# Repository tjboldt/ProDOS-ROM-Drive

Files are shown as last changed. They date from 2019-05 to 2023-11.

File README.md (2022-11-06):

# v4.0
This is a new revision of the hardware, incompatible with previous firmware and drive image before v3. If you have a v2.5 board, see the v2.5 tag [here](https://github.com/tjboldt/ProDOS-ROM-Drive/tree/v2.5). Note that all of v2.1, v2.5 and v3.0 have a small design mistake that didn't properly buffer the data bus the way it was intended in the original v1.0 version. This has been fixed for v4.0.

# ProDOS ROM-Drive
This is a peripheral card for the Apple ][ series computers that acts as a read-only solid state disk drive (SSD) all in EPROM. Although it won't run DOS, it is fully ProDOS compatible and will appear as a read-only hard drive even when booting from another drive. It holds 1024 KB of disk data with the 256 byte firmware stored in block 0001 where the SOS boot loader normally resides. The drive boots ProDOS and into BASIC in under 1.5 seconds. 

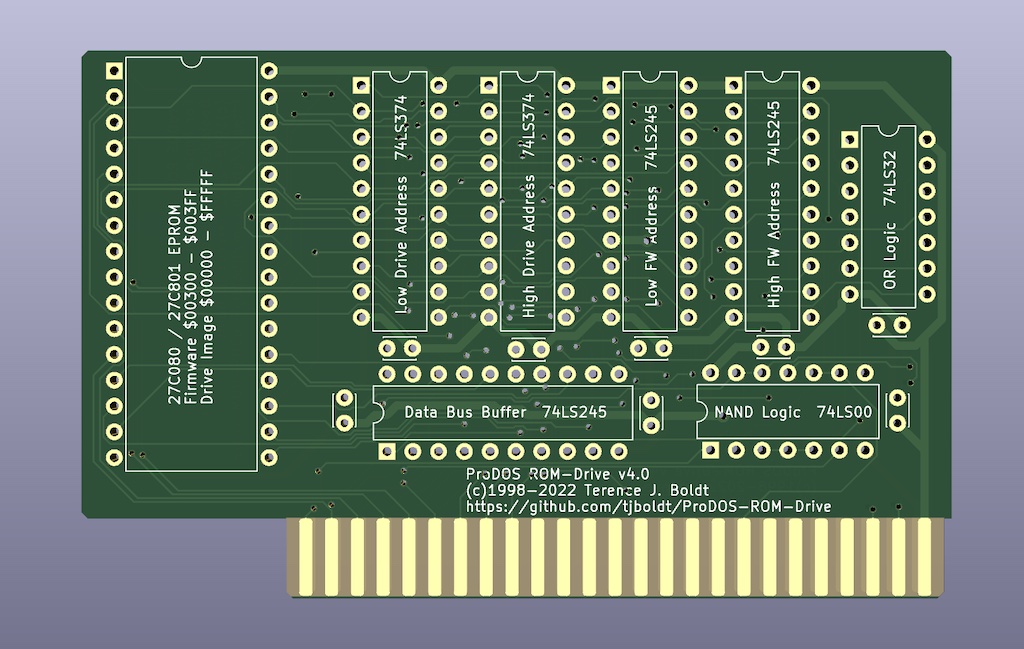
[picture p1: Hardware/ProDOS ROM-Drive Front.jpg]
Image of Board


You can order blank circuit boards from [PCBWay](https://www.pcbway.com/project/shareproject/ProDOS_ROM_Drive_v4_4fe0794f.html) or upload the provided gerber and drill files to any PCB manufacturer.

## History

My first Apple computer was an Apple //e that my brother bought in early 1984. Countless hours were spent playing games which developed my interest in building games. This also led to the creation of various utilities to help organize disks or just to see what could be done while programming.

As time passed, I obtained other machines far more powerful and eventually my once loved Apple IIe got used less and less. I did still pull it out of storage every few months to play some classic games or see what I could accomplish with greater programming skills. The problem was connecting up disk drives, looking for disks and hoping that the disks still worked. To make life simpler, I decided I needed to come up with some way to permanently store the files inside the computer without needing to plug in anything but the power and video connectors. This is where the idea for a solid-state drive began.

In the summer of 1998 I did some research in my own Apple II library for information on building peripheral cards. I drew up some designs in September 1998 and started building a prototype on a solderless breadboard with the wires jumpered over from a dead parallel card which I had cut the traces on. The rough idea at the time was to have two EPROMs. One would hold the 256 bytes of code in the $Cs00 - $CsFF space (where s is the slot number) and the second EPROM would get accessed through the 16 byte port space for the slot. To access more than 16 bytes, I would have a couple latch chips where you could program in the address of the disk EPROM and then read it one byte at a time through the ports. Originally I was going to make my own modified version of DOS 3.3 but before I got too far, David Wilson from Australia convinced me that it was much easier to build it for ProDOS since it supported many types of drives natively.

By November 1998 I had a prototype on the solderless breadboard that could read data from the EPROM but it had no driver code, didn't boot and was very unreliable. In December I managed to have the two EPROM based system running but it would fail to boot about 80% of the time with various read errors. Shortening the length of wires, cleaning up the layout and a new design helped but it was still unreliable. I finally gave up on the second design but as it turns out, it could have been fixed quite easily.

By mid-May of 1999 I finally got around to building a third design. This time I reduced the chip count and made the firmware for the drive reside in the top two blocks of the virtual disk EPROM. It still was somewhat unreliable in slot one but it was progressively worse as it was placed into higher slot numbers. By slot seven the card was completely unuseable. I then discovered that adding a 104 ceramic capacitor to each chip made the problem disappear. It was suddenly fully reliable.

To build actual circuit boards, I tried making some by hand with marker, etching solution and copper on fibreglass boards but this proved to be far too difficult. I then learned the wonders of gerber files which can be created with a variety of PCB layout software. The files were emailed to a company in Alberta, Canada and three days later in July of 1999 I received a batch of 10 blank boards. These boards did not have the familiar green board look to them, nor were they pre-cut. I had to cut and file them to fit an Apple II slot by hand. Back then it was prohitively expensive for a young hobbiest to make less than 20 or 30 boards with the full solder-masking process due to the set-up fees.

In 2019, I decided to revisit the original design as I was disappointed that the original didn't have a solder mask and was rather large for what it was. I got the board much smaller but in the process of translating my two decade old hand written notes, I made a mistake on one control line. To actually call this project finished, I had to make another revision. I also noticed the revised board was slightly larger than a credit card so I worked for a couple weeks to optimize the lines and squeeze the two-layer board down to 3.375" x 2.125". (Note that references above to first, second and third design are all the solderless breadboard prototypes leading up to the 1.0 circuit board printed in 1999, 2.0 was never made, 2.1 is the board with the error patched with a jumper wire and 2.2 through 2.4 were never made).

In 2021, the first ever issue was opened on the project requesting that the firmware be relocatable. I let that issue sit for a few months and then Ralle Palaveev supplied some relocatable firmware as a patch. I quickly realized that this could be placed into the second block on the drive normally reserved for SOS bootloader for the Apple ///, essentially allowing the full EPROM to be used for the drive. I disassembed Ralle's patch, merged it into the existing source code and made a few updates to save a few bytes and add clarity. This change required some differences in wiring for the firmware addressing on the card. The final revision 4.0 was made in 2022 to fix the data buffer wiring but was otherwise the same as 3.0.

## Notes
I used to use Ciderpress to copy files onto the drive image but now use my own cross-platform command line tool [ProDOS-Utilities](https://github.com/tjboldt/ProDOS-Utilities) and sometimes make modifications to the image live via an Apple II emulator. I then burn the file to a 27C801 EPROM with a GQ-4x4 USB Programmer. Do NOT overwrite block 0001 in the image as it contains the firmware for the card.

If you're planning on designing you own card, I highly recommend reading "Interfacing & Digital Experiments with your Apple" by Charles J. Engelisher and Apple's "Apple II Reference Manual" as well as "ProDOS Technical Reference Manual" if you want to build a drive. You also need an EPROM programmer, some chips and a prototyping board. My designs used simple logic gates to decode addresses but if you want to reduce chip count, you'll also need a PAL/GAL logic programmer (which some EPROM programmers can do).

## Website
Official website is [apple2.ca](http://apple2.ca/).

## Purchasing a ProDOS ROM-Drive
I generally no longer sell these cards but you can buy them online from [Laser](https://www.laser.com/product_info.php/item/ProDOS_ROM_Drive-Apple_II_ProDOS_bootable_1MB_read-only_drive/cPath/288_292/products_id/1984) and other retailers.

## Other links
- [Thread about building the card](https://tinkerdifferent.com/threads/building-tjboldts-prodos-rom-drive-for-apple.1249/)
- [Article about the card](https://www.callapple.org/hardware/prodos-rom-drive-version-3/)
- [Alternate version with fewer chips](https://www.ebay.com/itm/374004896438)

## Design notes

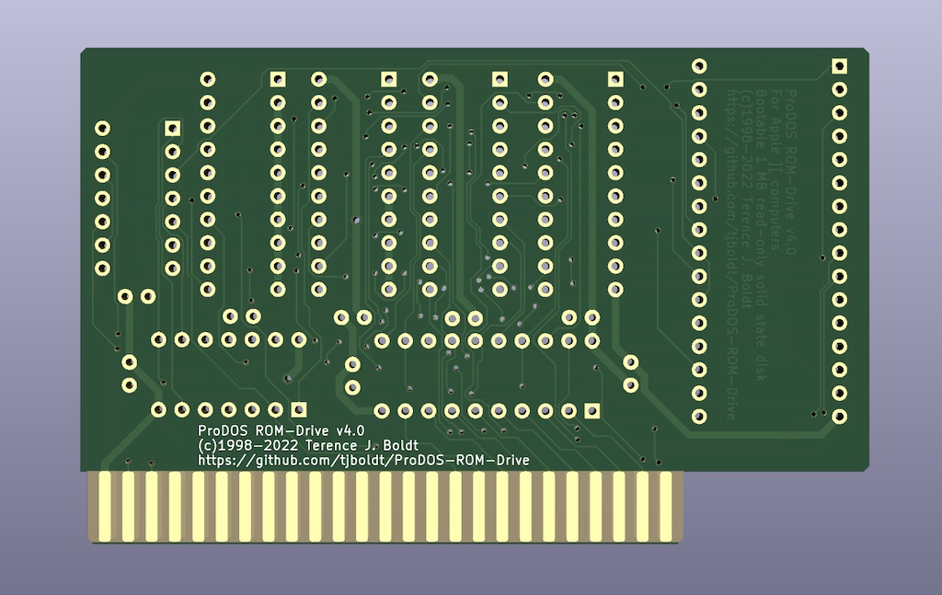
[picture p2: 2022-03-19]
Hardware/ProDOS ROM-Drive Back.jpg

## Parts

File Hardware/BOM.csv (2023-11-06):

Part | Quantity | Supplier Part # | Supplier
74LS32 | 1 | 595-SN74LS32N | Mouser
74LS00 | 1 | 595-SN74LS00N | Mouser
74LS245 | 3 | 595-SN74LS245N | Mouser
74LS374 | 2 | 595-SN74LS374N | Mouser
0.1µF Capacitor | 8 | 594-K104K15X7RF5TH5 | Mouser
14 Pin DIP Socket | 2 | 571-1-2199298-3 | Mouser
20 Pin DIP Socket | 5 | 571-1-2199298-6 | Mouser
32 Pin DIP Socket | 1 | 571-1-2199300-2 | Mouser
27C080 or 27C801 | 1 | Obsolete | eBay

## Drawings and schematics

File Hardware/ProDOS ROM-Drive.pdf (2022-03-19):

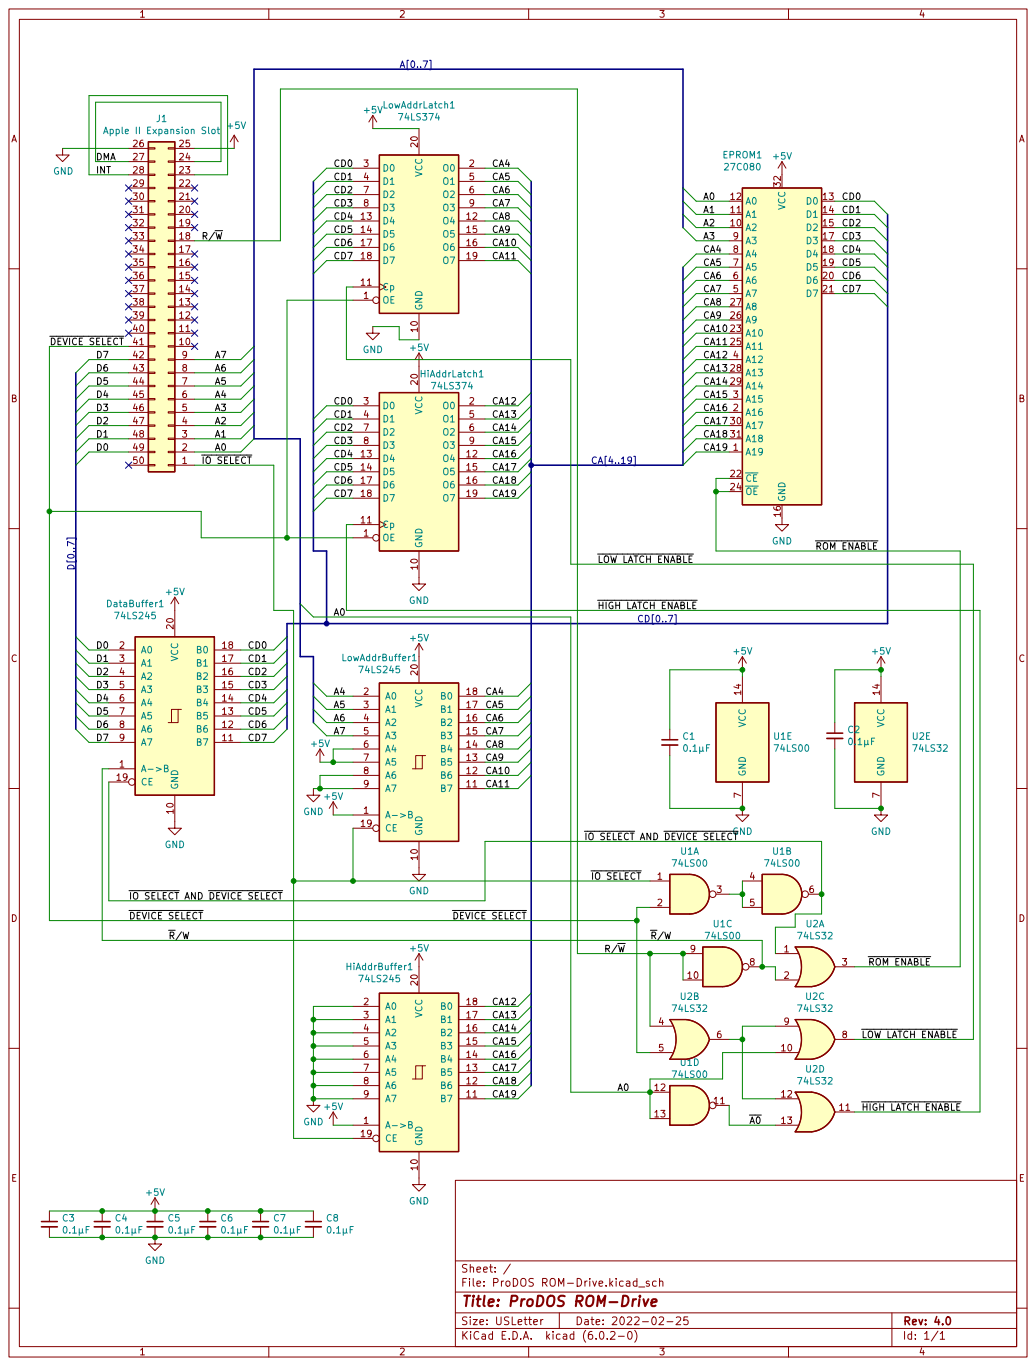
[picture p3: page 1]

Id: 1/1 Title: ProDOS ROM-Drive

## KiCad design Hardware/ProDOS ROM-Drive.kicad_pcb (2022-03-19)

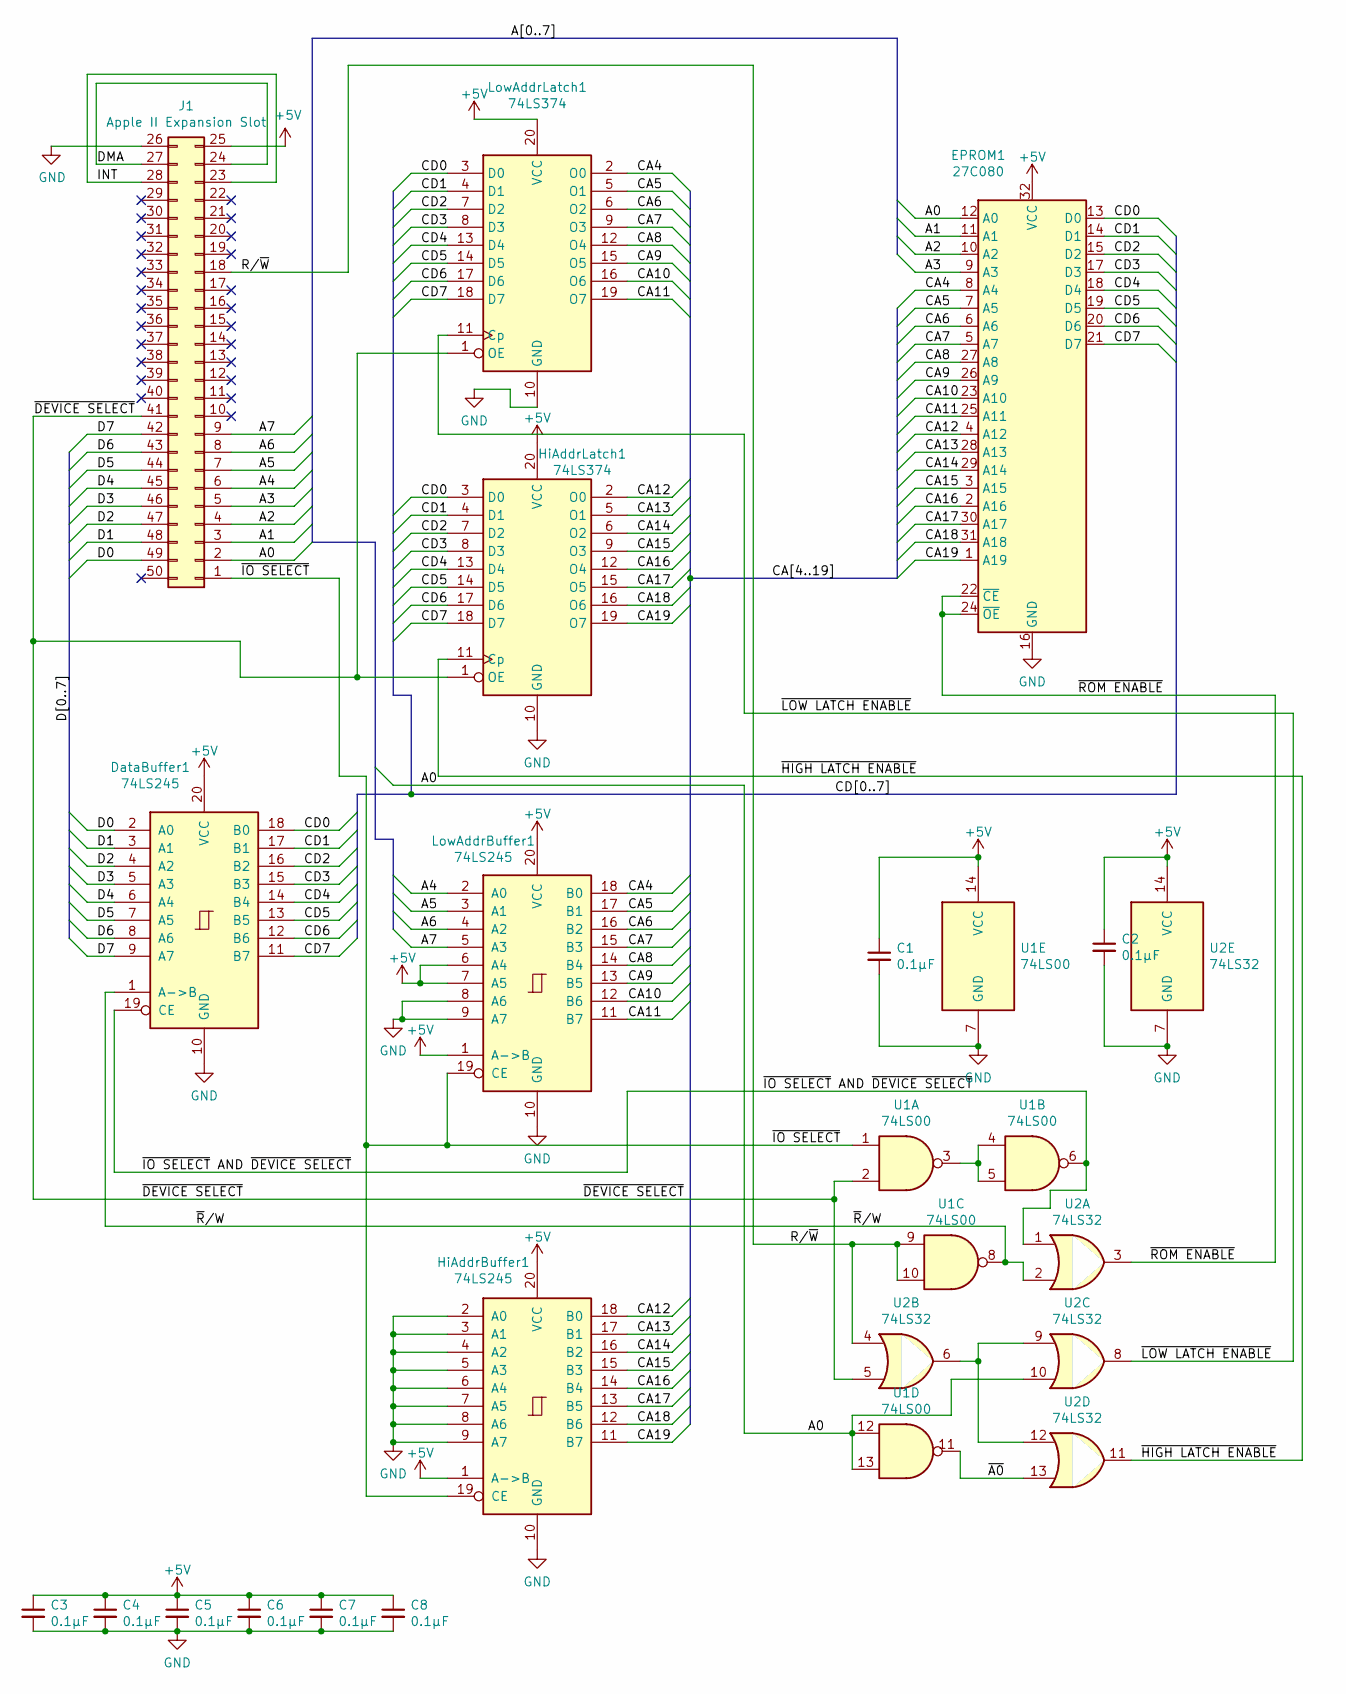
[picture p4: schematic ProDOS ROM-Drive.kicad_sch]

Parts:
C1, C2, C3, C4, C5, C6, C7, C8: 0.1µF; C_Disc_D3.0mm_W2.0mm_P2.50mm
DataBuffer1: 74LS245; DIP-20_W7.62mm
EPROM1: 27C080; DIP-32_W15.24mm
HiAddrBuffer1: 74LS245; DIP-20_W7.62mm
HiAddrLatch1: 74LS374; DIP-20_W7.62mm
J1: Apple II Expansion Slot; Apple II Expansion Edge Connector
LowAddrBuffer1: 74LS245; DIP-20_W7.62mm
LowAddrLatch1: 74LS374; DIP-20_W7.62mm
U1: 74LS00; DIP-14_W7.62mm
U2: 74LS32; DIP-14_W7.62mm

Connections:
+5V: C1.1, C2.1, C3.1, C4.1, C5.1, C6.1, C7.1, C8.1, DataBuffer1.20 (VCC), EPROM1.32 (VCC), HiAddrBuffer1.1 (A->B), HiAddrBuffer1.20 (VCC), HiAddrLatch1.20 (VCC), J1.25 (GND), LowAddrBuffer1.1 (A->B), LowAddrBuffer1.6 (A4), LowAddrBuffer1.7 (A5), LowAddrBuffer1.20 (VCC), LowAddrLatch1.20 (VCC), U1.14 (VCC), U2.14 (VCC)
/A0: EPROM1.12 (A0), J1.2, U1.12, U1.13, U2.10
/A1: EPROM1.11 (A1), J1.3
/A2: EPROM1.10 (A2), J1.4
/A3: EPROM1.9 (A3), J1.5
/A4: J1.6, LowAddrBuffer1.2 (A0)
/A5: J1.7, LowAddrBuffer1.3 (A1)
/A6: J1.8, LowAddrBuffer1.4 (A2)
/A7: J1.9, LowAddrBuffer1.5 (A3)
/CA4: EPROM1.8 (A4), LowAddrBuffer1.18 (B0), LowAddrLatch1.2 (O0)
/CA5: EPROM1.7 (A5), LowAddrBuffer1.17 (B1), LowAddrLatch1.5 (O1)
/CA6: EPROM1.6 (A6), LowAddrBuffer1.16 (B2), LowAddrLatch1.6 (O2)
/CA7: EPROM1.5 (A7), LowAddrBuffer1.15 (B3), LowAddrLatch1.9 (O3)
/CA8: EPROM1.27 (A8), LowAddrBuffer1.14 (B4), LowAddrLatch1.12 (O4)
/CA9: EPROM1.26 (A9), LowAddrBuffer1.13 (B5), LowAddrLatch1.15 (O5)
/CA10: EPROM1.23 (A10), LowAddrBuffer1.12 (B6), LowAddrLatch1.16 (O6)
/CA11: EPROM1.25 (A11), LowAddrBuffer1.11 (B7), LowAddrLatch1.19 (O7)
/CA12: EPROM1.4 (A12), HiAddrBuffer1.18 (B0), HiAddrLatch1.2 (O0)
/CA13: EPROM1.28 (A13), HiAddrBuffer1.17 (B1), HiAddrLatch1.5 (O1)
/CA14: EPROM1.29 (A14), HiAddrBuffer1.16 (B2), HiAddrLatch1.6 (O2)
/CA15: EPROM1.3 (A15), HiAddrBuffer1.15 (B3), HiAddrLatch1.9 (O3)
/CA16: EPROM1.2 (A16), HiAddrBuffer1.14 (B4), HiAddrLatch1.12 (O4)
/CA17: EPROM1.30 (A17), HiAddrBuffer1.13 (B5), HiAddrLatch1.15 (O5)
/CA18: EPROM1.31 (A18), HiAddrBuffer1.12 (B6), HiAddrLatch1.16 (O6)
/CA19: EPROM1.1 (A19), HiAddrBuffer1.11 (B7), HiAddrLatch1.19 (O7)
/CD0: DataBuffer1.18 (B0), EPROM1.13 (D0), HiAddrLatch1.3 (D0), LowAddrLatch1.3 (D0)
/CD1: DataBuffer1.17 (B1), EPROM1.14 (D1), HiAddrLatch1.4 (D1), LowAddrLatch1.4 (D1)
/CD2: DataBuffer1.16 (B2), EPROM1.15 (D2), HiAddrLatch1.7 (D2), LowAddrLatch1.7 (D2)
/CD3: DataBuffer1.15 (B3), EPROM1.17 (D3), HiAddrLatch1.8 (D3), LowAddrLatch1.8 (D3)
/CD4: DataBuffer1.14 (B4), EPROM1.18 (D4), HiAddrLatch1.13 (D4), LowAddrLatch1.13 (D4)
/CD5: DataBuffer1.13 (B5), EPROM1.19 (D5), HiAddrLatch1.14 (D5), LowAddrLatch1.14 (D5)
/CD6: DataBuffer1.12 (B6), EPROM1.20 (D6), HiAddrLatch1.17 (D6), LowAddrLatch1.17 (D6)
/CD7: DataBuffer1.11 (B7), EPROM1.21 (D7), HiAddrLatch1.18 (D7), LowAddrLatch1.18 (D7)
/D0: DataBuffer1.2 (A0), J1.49
/D1: DataBuffer1.3 (A1), J1.48
/D2: DataBuffer1.4 (A2), J1.47
/D3: DataBuffer1.5 (A3), J1.46
/D4: DataBuffer1.6 (A4), J1.45
/D5: DataBuffer1.7 (A5), J1.44
/D6: DataBuffer1.8 (A6), J1.43
/D7: DataBuffer1.9 (A7), J1.42
/DMA: J1.24, J1.27
/INT: J1.23, J1.28
/R/~W: J1.18, U1.9, U1.10, U2.4
/~A0: U1.11, U2.13
/~DEVICE SELECT: HiAddrLatch1.1 (OE), J1.41, LowAddrLatch1.1 (OE), U1.2, U2.5
/~HIGH LATCH ENABLE: HiAddrLatch1.11 (Cp), U2.11
/~IO SELECT: HiAddrBuffer1.19 (CE), J1.1, LowAddrBuffer1.19 (CE), U1.1
/~IO SELECT AND ~DEVICE SELECT: DataBuffer1.19 (CE), U1.6, U2.1
/~LOW LATCH ENABLE: LowAddrLatch1.11 (Cp), U2.8
/~ROM ENABLE: EPROM1.22 (~CE), EPROM1.24 (~OE), U2.3
/~R/W: DataBuffer1.1 (A->B), U1.8, U2.2
GND: C1.2, C2.2, C3.2, C4.2, C5.2, C6.2, C7.2, C8.2, DataBuffer1.10 (GND), EPROM1.16 (GND), HiAddrBuffer1.2 (A0), HiAddrBuffer1.3 (A1), HiAddrBuffer1.4 (A2), HiAddrBuffer1.5 (A3), HiAddrBuffer1.6 (A4), HiAddrBuffer1.7 (A5), HiAddrBuffer1.8 (A6), HiAddrBuffer1.9 (A7), HiAddrBuffer1.10 (GND), HiAddrLatch1.10 (GND), J1.26 (+5V), LowAddrBuffer1.8 (A6), LowAddrBuffer1.9 (A7), LowAddrBuffer1.10 (GND), LowAddrLatch1.10 (GND), U1.7 (GND), U2.7 (GND)
unnamed: U1.3, U1.4, U1.5
unnamed: U2.6, U2.9, U2.12

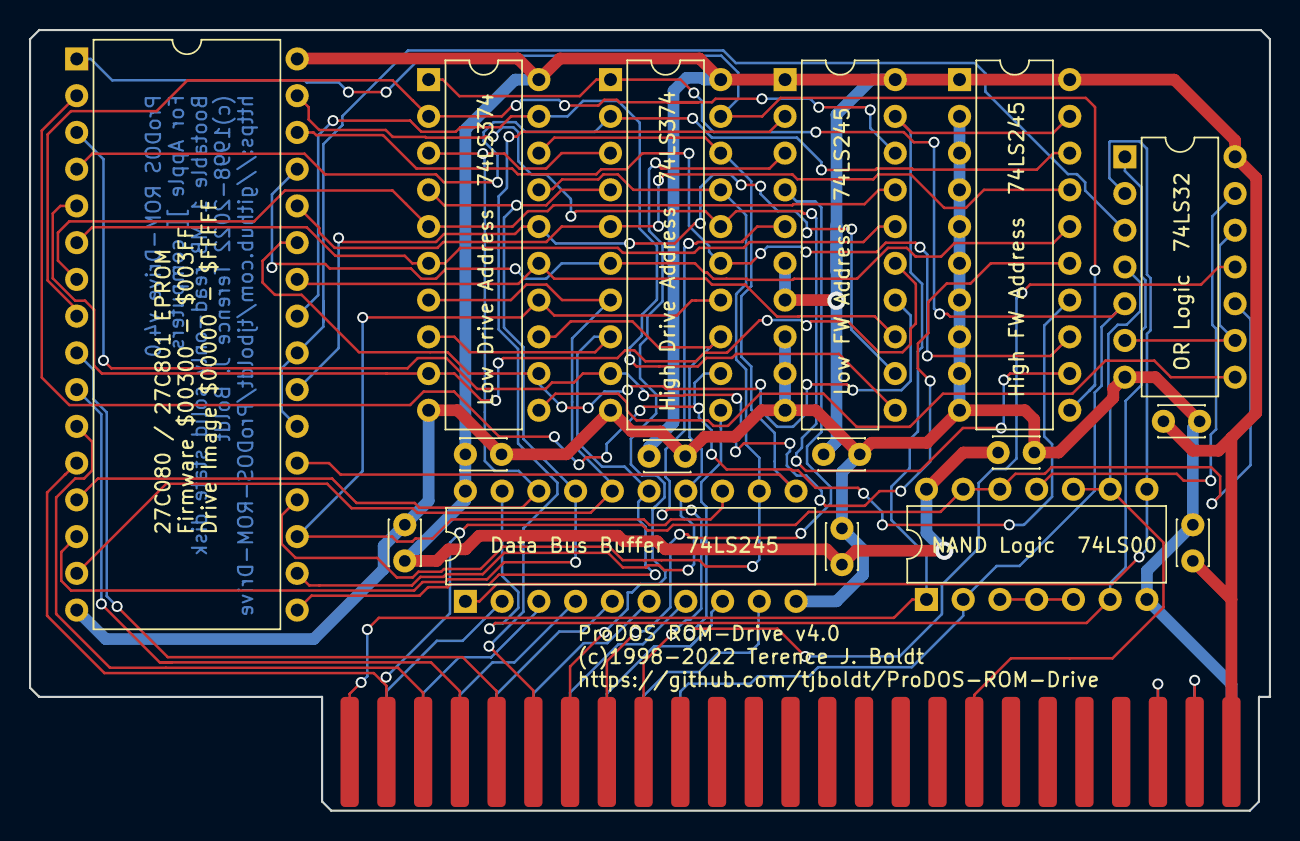
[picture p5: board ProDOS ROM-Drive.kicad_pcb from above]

Board: 2 copper layers, 85.7 x 54.0 mm, 17 parts (0 on the bottom side), 55 nets.

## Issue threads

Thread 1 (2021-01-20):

Determine slot from within firmware

dgorski, 2021-01-20:
I ran across this project (ProDOS-ROM-Drive) of yours while researching my own apple2 IO board project.

During my reasearch I found this article from Apple which contains code that can determine the slot number it is executing from.  I thought this could be of interest for this project or your other project (Apple2-IO-RPi).

[Apple II Hobby and Prototyping Board Manual](https://www.apple.asimov.net/documentation/hardware/io/Apple%20II%20Hobby%20and%20Prototyping%20Board%20Manual.pdf)

The relevant code is at the bottom of page 6.  Hope this is useful, keep up the good work!

- Darrin

tjboldt, 2021-01-20:
Thanks for the link. That’s a great resource. I am already doing something similar in my [other project](https://github.com/tjboldt/Apple2-IO-RPi) but I found it easier for both projects to simply use a separate 256 bytes of firmware for each slot and use the address lines to access it. This allows jumps to subroutines (JSR) within the firmware which is difficult to do otherwise in 6502 assembler with relative code.

tjboldt, 2021-09-15:
Reopening as more than one person has asked about making this relative code. It's not necessary to make the card work but could reduce the wasted space for firmware and allow for a few extra blocks on the ProDOS volume.

rallepalaveev, 2021-09-16:
Hi I am using this address self-determining code in the firmware I use for my cards posted on my profile. :)

rallepalaveev, 2021-12-04:
Hi, just a heads up - I programmed the relative code for the ROM drive in a simulator, I only need to test it on the real hardware, which I'd do over the Christmas break, then I'll share. Happy holidays!

Daniel102010, 2021-12-04:
Thanks for let me know, Happy Christmas 🎄 and Happy Holiday. Regards Daniel 

Sent from Yahoo Mail for iPhone

On Saturday, December 4, 2021, 9:39 a.m., Ralle Palaveev ***@***.***> wrote:

Hi, just a heads up - I programmed the relative code for the ROM drive in a simulator, I only need to test it on the real hardware, which I'd do over the Christmas break, then I'll share. Happy holidays!

—
You are receiving this because you are subscribed to this thread.
Reply to this email directly, view it on GitHub, or unsubscribe.

tjboldt, 2021-12-04:
If you submit a PR, I can test the firmware changes for you.

rallepalaveev, 2021-12-04:
Sure, here it is. Let me know if it wor
[BlankDriveWithFirmware-RP-patch.zip](https://github.com/tjboldt/ProDOS-ROM-Drive/files/7653800/BlankDriveWithFirmware-RP-patch.zip)
ks

tjboldt, 2021-12-04:
It would be more interesting to wire it up so that it reads the firmware from block $0001 instead of block $0800. Block $0001 is reserved for Apple /// SOS and not used by ProDOS so the firmware could reside there instead.

rallepalaveev, 2021-12-04:
I can do that, but it would require hardware changes too. The two 74LS245 buffers must be wired such that they address $200-$2FF of the EPROM upon I/O Select active. All bits of the high byte go low and on the low byte - bits 0-3 to A0-A3, bits 4,6,7 to ground and bit 5 to power. And the firmware should work as it is now from there. Provided that there are no bugs and it is functional, as I have not tested it yet.

tjboldt, 2021-12-08:
I burned your firmware patch onto an EPROM and tested the card. It does indeed work. Thanks. I am going to make some physical modifications to a spare board to see if it will work placing the code in block $0001, effectively freeing the entire EPROM for use as a drive. If you want to have credit for your work, fork the project and submit a pull request. When I merge, you will appear as one of the contributors of this project. Likely there will be a v3.0 of this board coming.

rallepalaveev, 2021-12-08:
Hi, I am glad it worked! I would be expecting the newly wired card - v3.0, take care!

tjboldt, 2021-12-10:
Firmware patch has been merged into the repo. Additional enhancements to hardware and updating firmware source will be done separately. Closing this issue.

Closed 2021-12-10.

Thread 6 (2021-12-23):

Text not displaying on boot

rallepalaveev, 2021-12-23:
I reviewed the code and have just a minor comment: $Cn26 should be "0D" and $CnEA should be "A0".

tjboldt, 2021-12-23:
Thanks Ralle,

I see that because Y has changed to start at a non-zero value, this line had to be changed (which goes from DO to OD):

sta $07D0-<text,y ;put text on last line

The byte at $CnEA is the null terminator for the string so I'm not sure why it should be A0 which would be a space

See related pull request

rallepalaveev, 2021-12-23:
It is the last character on the line and it prints inverted @

tjboldt, 2021-12-24:
I updated this to instead not scribble over the scratch RAM but stop printing when null terminator reached.

Closed 2021-12-24.

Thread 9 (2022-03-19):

Random read failures

tjboldt, 2022-03-19:
In a stress test, sometimes there are random read failures. This appears to be caused by an oversight where the data lines are not properly buffered. This mistake was made because the schematic was hard to read. It was found cleaning up #8 .

Closed 2022-03-19.

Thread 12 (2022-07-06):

Crashing with error on bootup

StormTrooper, 2022-07-06:
I'm having issues getting this to boot and wondering if you are able to point me in the right direction.

I've build one of these cards and have written the GamesWithFirmware.po to a 27C801 and verified ok. Have also tested all the logic chips and double checked my soldering - all good.

When I bootup the computer ProDOS starts but it crashes with a error on startup.

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

I don't have access to a disk drive to test a normal bootup but have run the internal diagnostics (Apple iie Enhanced) and get the system ok.

StormTrooper, 2022-07-06:
Ver 4 with the v4 firmware.

tjboldt, 2022-07-06:
I’ll assume all 0.1 uF capacitors are in place? A bad or missing cap will do that too. Have you tried the card in other slots? And of course always power off the computer when adding or removing cards. You probably know all this though given your skill level soldering and testing components.

StormTrooper, 2022-07-07:
Yes, all the caps are in place.  I've tried the card in other slots and still experience the same issue. Not really sure what to check next. I've retested the logic chips and they are all ok.

At first I suspected a faulty RAM Chip on the Apple but it passes the internal diag test.

tjboldt, 2022-07-07:
Do you have an extended 80 column card installed? The person who helped create the relocatable version of the firmware noted that ProDOS was failing to boot with only 64 KB of RAM instead of 128 KB. He has a fix but I haven't had time to integrate and test it.

StormTrooper, 2022-07-07:
I have a Saturn 128k extended card as well as another extended 80 col card. Tried each one - didn't make any difference.

StormTrooper, 2022-07-08:
I've also got a Apple IIe diagcard and run the ram test on loop and there are no failures.

Have also build another card with different components and still getting the same error so am really out of ideas now.

tjboldt, 2022-07-12:
I believe this may be a firmware bug. There is a new firmware in the works that should be ready to test this week.

tjboldt, 2022-07-12:
@StormTrooper can you pull from the `firmware-fix` branch and try that image? I made some changes based on recommendations from @rallepalaveev plus a few other tweaks. It works on my machine now even with the extended 80 column card removed.

StormTrooper, 2022-07-13:
Great stuff. I can confirm it's working for me as well.

Thanks

Closed 2022-07-13.

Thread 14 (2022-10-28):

Key to skip slot during boot

Alex-Kw, 2022-10-28:
I'm wondering if the firmware could be modified to have a skip on boot key, similar to the MicroDrive or a recent patch for the Dan ][ SD card. For reference:

https://www.applefritter.com/comment/99467#comment-99467

Being able to hold escape or a different key during poweron to skip the ROM drive would be a very useful feature. Thanks for your consideration.

tjboldt, 2022-10-30:
That is a good idea although note that it will only work when the RPi is connected since the firmware address selection is controlled by 3.3V powered chips. I can add this to the next firmware release.

Alex-Kw, 2022-10-30:
Terence,

In this case I'm referring to a ProDOS Rom drive in Slot 7 (for example) of a real machine, with a normal Apple disk controller in slot 6. Normally the card in slot 7 would take precedence, but the suggestion is that holding escape or another key on the Apple IIe / IIgs during poweron would skip the ProDOS ROM Drive and proceed to Floppy drives or the other slots. I do know the MicroDrive turbo which acts in this manner has 2 separate firmwares but I don't know if this feature is coded differently in the two versions (Apple II vs IIGS firmware).

tjboldt, 2022-10-31:
Hi Alex,

Sorry, I was replying from my phone and thought this was my other project. For this project, it should be relatively simple to add the ESC to skip boot. Note that it boots very fast so you'd probably need to hold ESC while booting. I'll try and have a firmware change in sometime in the next week or so.

Alex-Kw, 2022-10-31:
Of course, no problem, and thank you.

And to echo, I agree that It would be expected to have to already have the ESC key down on boot, as like you said, the boot sequence is extremely fast.

Cheers

Closed 2022-11-06.

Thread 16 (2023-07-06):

Card is compatible with Titan Accelerator IIe -- in fast mode!

buserror, 2023-07-06:
Not a bug, but I don't know how to report that anywhere else!

I just got a 3.5Mhz Accelerator IIe card, and I tried first in 'slow mode' where you configure the card to slow down accesses to the slot you want, as well as slow down the access to the IO memory.
It works fine of course, but then I tried to disable the slowdown on both card and IO memory access and ... it still works great!

So well done ;-)

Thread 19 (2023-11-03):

Where is the BOM?

Verault, 2023-11-03:
I am trying to find a BOM just for the sake of parts ordering and keeping proper notes. I can't seem to find the BOM, am I missing it?

Closed 2023-11-06.

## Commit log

2019-05-13 Initial push to git
    [ProDOS ROM-Drive 2.5-B.Cu.gbr, ProDOS ROM-Drive 2.5-B.Mask.gbr, ProDOS ROM-Drive 2.5-Edge.Cuts.gbr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]
2019-05-13 Adding blank ProDOS drive with firmware assembled in top 2KB
2019-05-14 Made image of board smaller
2019-10-20 Add missing schematic files as they were part of revision 2.2 where PCB was 2.5
    [ProDOS ROM-Drive 2.2.sch]
2020-12-01 Update assembler code to work with modern version of cc65 tools
2020-12-01 Update assembly instructions
2021-12-10 Update hardware to use block 0001 for firmware
    [ProDOS ROM-Drive 2.5-B.Cu.gbr, ProDOS ROM-Drive 2.5-B.Mask.gbr, ProDOS ROM-Drive 2.5-F.Cu.gbr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]
2021-12-12 Update firmware source to be relocatable
    [ProDOS ROM-Drive 3.0-B_Cu.gbr, ProDOS ROM-Drive 3.0-B_Mask.gbr, ProDOS ROM-Drive 3.0-Edge_Cuts.gbr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]
2021-12-22 Fixed firmware for v3 board
2022-02-24 Rename files without version
    [ProDOS ROM-Drive-B_Cu.gbr, ProDOS ROM-Drive-B_Mask.gbr, ProDOS ROM-Drive-Edge_Cuts.gbr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]
2022-02-24 Ignore KiCAD 6 backups
2022-02-24 Update to KiCAD 6
    [ProDOS ROM-Drive.kicad_pcb, ProDOS ROM-Drive.kicad_sch, ProDOS ROM-Drive.sch]
2022-03-19 Update schematic and fix data bus lines
    [ProDOS ROM-Drive-B_Cu.gbr, ProDOS ROM-Drive-B_Mask.gbr, ProDOS ROM-Drive-B_Silkscreen.gbr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]
2022-03-19 Updated gerber files to be compatible with PCBWay
    [ProDOS ROM-Drive-B_Cu.gbr, ProDOS ROM-Drive-B_Mask.gbr, ProDOS ROM-Drive-B_Silkscreen.gbr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]
2022-07-12 Update driver to not need JSR $FF58 on entry
    Save and restore zero page values
2022-11-02 Add ESC to skip boot to next slot
2022-11-06 Add boot slot 1 - 7 in startup menu
2023-11-06 Add BOM, closes #19
    [BOM.csv]
2026-02-26 Assemble latest firmare and update copyright

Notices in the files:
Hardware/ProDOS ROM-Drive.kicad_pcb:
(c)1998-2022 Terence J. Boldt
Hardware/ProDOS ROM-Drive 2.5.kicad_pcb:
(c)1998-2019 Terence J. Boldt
